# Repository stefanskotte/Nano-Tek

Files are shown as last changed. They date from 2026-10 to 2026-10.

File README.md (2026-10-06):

# Nano-Tek

**Note: This branch uses a PCB with the 34 pin floppy header is rotated 180 degrees to allow better fitment in some Amiga models. Everything else is the same with the main branch.**

A tiny, modern reimagining of the classic **Gotek** floppy-disk-drive emulator. Nano-Tek keeps the full feature set of a Gotek-style FDD emulator but packs it onto a board that is a fraction of the size, hence the name *Nano*-Tek.

<p align="center">
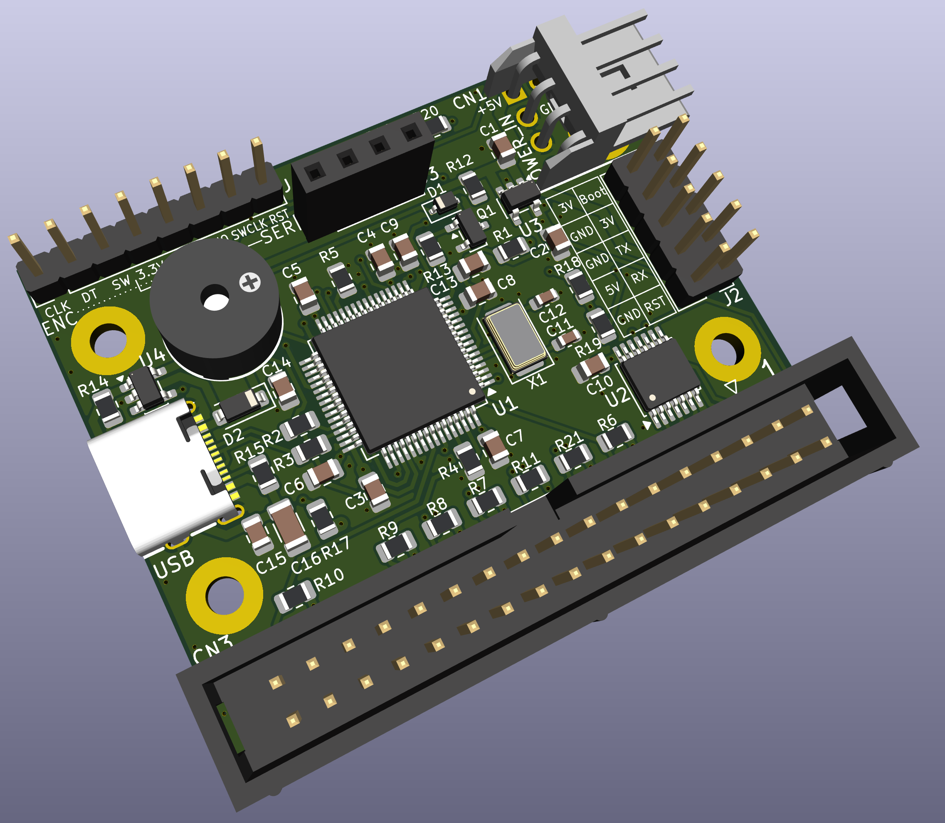
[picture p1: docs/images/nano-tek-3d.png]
Nano-Tek PCB, 3D render
  
</p>

The schematic is derived from the open-source [**OpenFlops**](https://github.com/SukkoPera/OpenFlops) design by *SukkoPera*, re-laid-out on a compact 4-layer PCB.

## Highlights

- **A lot smaller.** The board measures just **51 × 42 mm**, roughly half the footprint of a standard Gotek, while keeping the same 34-pin floppy interface.
- **FlashFloppy-compatible.** Built around the **STM32F105RBT6** (Cortex-M3) MCU, so it runs the popular [FlashFloppy](https://github.com/keirf/flashfloppy) firmware.
- **USB-C.** A modern USB-C port for the USB stick, fed through a current-limited power switch. It can also power the board on the bench.
- **OLED + rotary encoder** headers for a clean front-panel UI.
- **On-board passive buzzer** for the drive-step "click" and FlashFloppy's notification beeps.
- **Easy first flash.** Serial (with a BOOT0 jumper) and SWD headers on board, so a blank chip can be programmed without extra wiring.
- **4-layer PCB** for clean power and signal routing in a small area.

## Hardware overview

| Function | Part / Connector | Ref |
|---|---|---|
| Microcontroller | STM32F105RBT6 (LQFP-64) | U1 |
| Bus buffer | 74LCX07 (TSSOP-14) | U2 |
| 3.3 V regulator | AP2112K-3.3 (SOT-23-5) | U3 |
| USB power switch  | SY6288DAAC, current-limited (SOT-23-5) | U4 |
| USB bench power | B5819W Schottky diode (USB-C to +5 V) | D2 |
| Clock | 8 MHz crystal | X1 |
| Floppy interface  | 34-pin IDC header | CN3 |
| Power input | 4-pin power connector (171826-4) | CN1 |
| USB | USB-C (SMD) | CN2 |
| Display | OLED header (I²C) | J3 |
| Input + debug | Rotary encoder + SWD header (1×8) | J4 |
| Programming | Serial + BOOT0 header (2×5) | J2 |
| Audio | Passive buzzer, 9 mm (QMB-09B-05) | J1 |

See [`Nano-Tek.pdf`](Nano-Tek.pdf) for the full schematic and [`jlcpcb/production_files/BOM-Nano-Tek.csv`](jlcpcb/production_files/BOM-Nano-Tek.csv) for the complete bill of materials.

## Repository layout

```
Nano-Tek.kicad_pro      KiCad 10 project
Nano-Tek.kicad_sch      Schematic
Nano-Tek.kicad_pcb      PCB layout (4-layer)
Nano-Tek.pretty/        Project-specific footprint library
3dmodels/               3D models for connectors/parts
docs/                   Builder's guide, ST-LINK/V2 label
docs/images/            Rendered board images
jlcpcb/                 Gerbers, BOM and CPL for JLCPCB assembly
Nano-Tek.pdf            Schematic export
```

## Manufacturing

Ready-to-order production files for **JLCPCB** (4-layer) are provided in
[`jlcpcb/production_files/`](jlcpcb/production_files/):

- `GERBER-Nano-Tek.zip`: Gerber + drill files
- `BOM-Nano-Tek.csv`: bill of materials (with LCSC part numbers)
- `CPL-Nano-Tek.csv`: component placement / pick-and-place

## Firmware

A new board needs its first [FlashFloppy](https://github.com/keirf/flashfloppy) flash over **serial** (J2, BOOT0 jumper on pins 9–10) or **SWD** (J4, ST-Link). USB-C (DFU) does not work on a blank chip; it is only for recovery once FlashFloppy is on the board. Download the release zip from the [FlashFloppy releases page](https://github.com/keirf/flashfloppy/releases) and use `hex/flashfloppy-at415-st105-<ver>.hex` from it.

Step-by-step wiring for USB-serial adapters, PL2303 cables, ST-Link clones and the official ST-LINK/V2 is in the [builder's guide](docs/Nano-Tek_First_Firmware_Flash_Builders_Guide.pdf). After the first flash, update from a USB stick: copy the `.upd` file to the stick and hold the encoder button at power-on.

> **Note:** The USB-C port is a host port. Use a USB-A to USB-C data cable to power the board from a PC; USB-C to USB-C cables don't power it.

## Revisions

- **Rev 1.3** (October 2026): on-board passive buzzer, USB power switch, J2 serial pins now match the silkscreen, PA9/PA10/PA3 pull-ups, /MOTOR on PA15, NRST on J4 pin 8.
- **Rev 1.0–1.2:** J2 TX/RX are swapped against the silkscreen, and D1 must be fitted across the speaker (not in series) for sound. The builder's guide marks the steps that differ.

## Credits & license

- Schematic derived from [OpenFlops](https://github.com/SukkoPera/OpenFlops) by **SukkoPera**.
- Firmware: [FlashFloppy](https://github.com/keirf/flashfloppy) by **Keir Fraser**.
- Thanks to Vinny, Mesarim, Screemo, Kavanoz, Wrangler and Ordyne.

Please check the upstream OpenFlops project for its licensing terms; this derivative is shared in the same open-hardware spirit.

---

*Nano-Tek: the Gotek, shrunk.* Rev 1.3.

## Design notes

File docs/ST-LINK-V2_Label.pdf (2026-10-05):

# ST-LINK/V2 (20-pin) pinout labels

Print at 100% / Actual size. Check the 50 mm bar, then cut along the dashed lines.

50 mm

ST-LINK/V2 20-pin JTAG/SWD

1 VAPP | 3 TRST | 5 TDI | 7 SWDIO | 9 SWCLK | 11 NC | 13 SWO | 15 NRST | 17 NC | 19 3V3 out
2 VAPP | 4 GND | 6 GND | 8 GND | 10 GND | 12 GND | 14 GND | 16 GND | 18 GND | 20 GND

Pin 1 = red stripe. SWD: 1 VAPP to target 3.3V (required), 7, 9, GND. Never connect 19.

Main label - stick next to the 20-pin header, pin 1 (triangle) on the red-stripe side.

ST-LINK/V2 → Nano-Tek (SWD)

1 VAPP | → | J4-4 +3V3
4 GND | → | J4-5 GND
7 SWDIO | → | J4-6 SWDIO
9 SWCLK | → | J4-7 SWCLK
15 NRST | → | J2-1 NRST (opt.)

FlashFloppy on chip: BOOT0 high (J2 9-10) for SWD

Wiring card - keep with the ST-LINK or on the jumper-wire bundle.

ST-LINK/V2 20-pin JTAG/SWD

1 VAPP | 3 TRST | 5 TDI | 7 SWDIO | 9 SWCLK | 11 NC | 13 SWO | 15 NRST | 17 NC | 19 3V3 out
2 VAPP | 4 GND | 6 GND | 8 GND | 10 GND | 12 GND | 14 GND | 16 GND | 18 GND | 20 GND

Pin 1 = red stripe. SWD: 1 VAPP to target 3.3V (required), 7, 9, GND. Never connect 19.

Compact copy (7 mm cells)

Finding pin 1 on the box header with a meter (probe unplugged):
- The even row is the one where 9 pins (4, 6 ... 20) are all GND; its one non-GND end pin is pin 2.
- Pin 1 is next to pin 2 in the other row (pins 1 and 2 are both VAPP and read shorted).
VAPP only senses the target voltage; the ST-LINK/V2 does not power the target.
Pin 19 is the probe's own 3.3 V output - leave it unconnected.
Source: ST UM1075, Table 4 (JTAG/SWD cable connections).

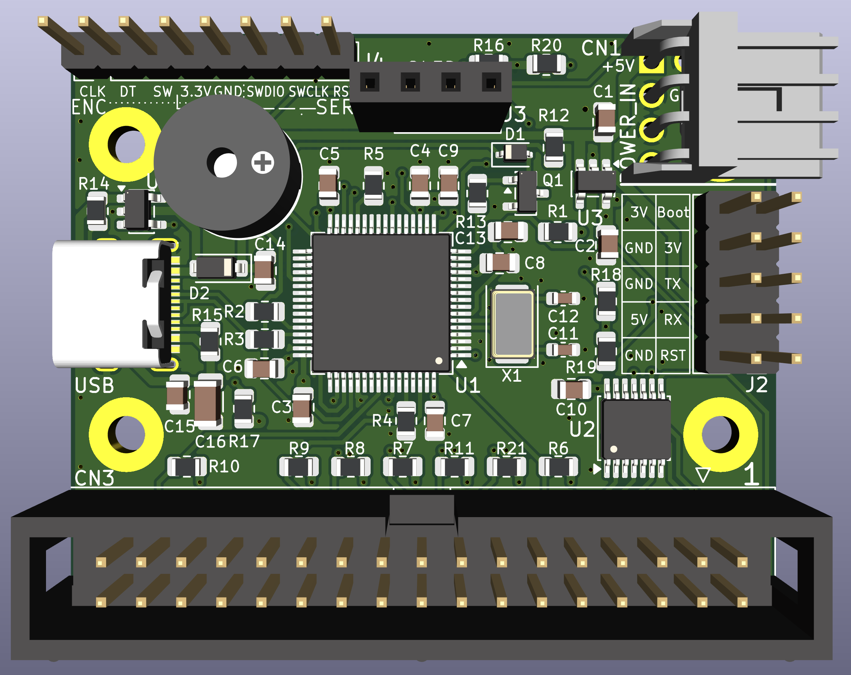
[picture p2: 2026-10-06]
docs/images/nano-tek-top.png

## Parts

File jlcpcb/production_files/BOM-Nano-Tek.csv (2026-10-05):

Comment | Designator | Footprint | LCSC | Quantity
100nF | C10,C13,C4,C5,C6,C7,C8 | C_0805_2012Metric | C49678 | 7
10K | R16,R17,R18,R19,R20 | R_0805_2012Metric | C17414 | 5
10uF | C14,C15,C2,C3,C9 | C_0805_2012Metric | C15850 | 5
1K | R10,R11,R13,R21,R6,R7,R8,R9 | R_0805_2012Metric | C17513 | 8
1N4148WS | D1 | D_SOD-323 | C2128 | 1
1uF | C1 | C_0805_2012Metric | C28323 | 1
22 | R12,R2,R3 | R_0805_2012Metric | C17561 | 3
30pF | C11,C12 | C_0603_1608Metric | C1658 | 2
47uF 10V | C16 | C_1206_3216Metric | C96123 | 1
4K7 | R1,R4,R5 | R_0805_2012Metric | C17673 | 3
51K | R14,R15 | R_0805_2012Metric | C17737 | 2
74LCX07 | U2 | TSSOP-14_4.4x5mm_P0.65mm | C2676034 | 1
8MHz | X1 | Crystal_SMD_5032-2Pin_5.0x3.2mm | C115962 | 1
AP2112K-3.3 | U3 | SOT-23-5 | C23380830 | 1
B5819W SL | D2 | D_SOD-123 | C8598 | 1
Buzzer | J1 | BUZ-TH_BD9.0-P4.00-D0.6-FD | C161819 | 1
Encoder+SER | J4 | PinHeader_1x08_P2.54mm_Vertical | C5383116 | 1
Floppy 34 | CN3 | IDC-Header_2x17_P2.54mm_Vertical | C601943 | 1
MMBT3904 | Q1 | SOT-23 | C20526 | 1
OLED | J3 | PinSocket_1x04_P2.54mm_Vertical | C41431927 | 1
POWER_IN | CN1 | 171826-4 | C590635 | 1
STM32F105RBT6 | U1 | LQFP-64_10x10mm_P0.5mm | C8349 | 1
SY6288DAAC | U4 | SOT-23-5 | C83700 | 1
USB | CN2 | USB-C-SMD_TYPE-C16PIN | C393939 | 1
USB_Prog | J2 | PinHeader_2x05_P2.54mm_Vertical | C5383106 | 1

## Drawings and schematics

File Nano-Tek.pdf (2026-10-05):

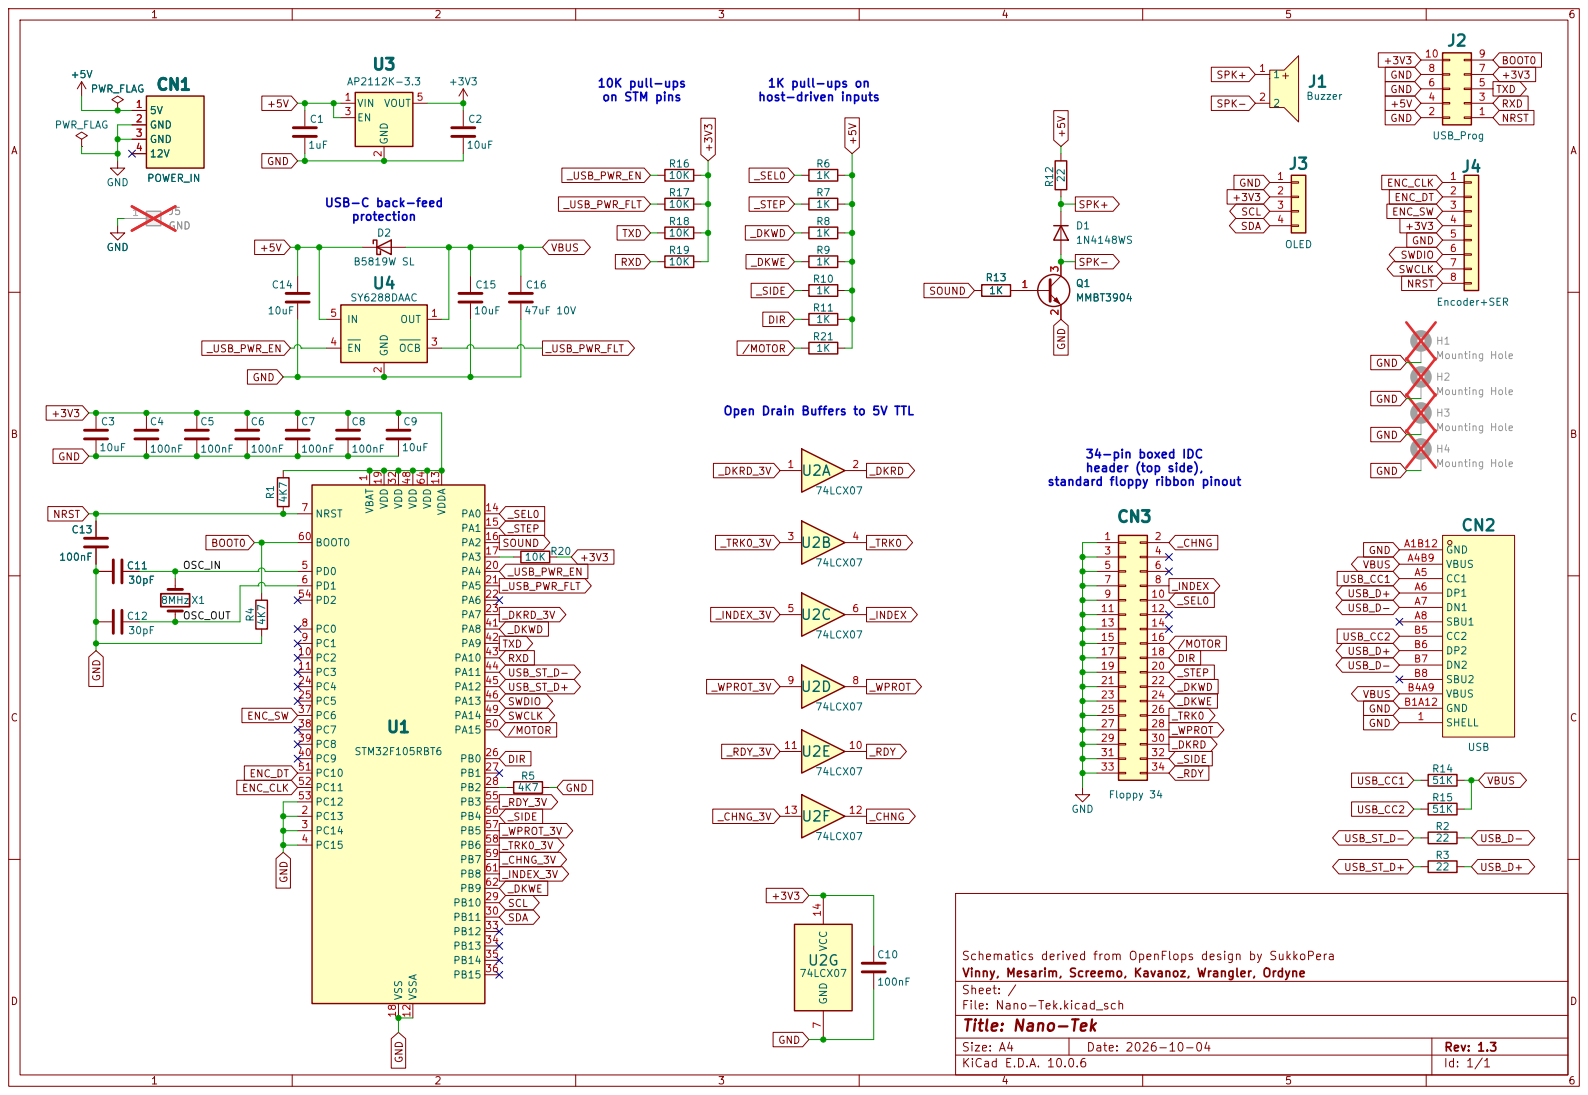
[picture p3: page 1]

2 3 Q1MMBT3904 H3Mounting Hole H4Mounting Hole H2Mounting Hole H1Mounting Hole 1

Open Drain Buffers to 5V TTL

34-pin boxed IDC
header (top side),
standard floppy ribbon pinout

Schematics derived from OpenFlops design by SukkoPera
Vinny, Mesarim, Screemo, Kavanoz, Wrangler, Ordyne
Sheet: /
File: Nano-Tek.kicad_sch
Title: Nano-Tek

Size: A4 | Rev: 1.3
KiCad E.D.A. 10.0.6 | Id: 1/1

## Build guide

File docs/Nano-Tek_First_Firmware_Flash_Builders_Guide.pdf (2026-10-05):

# Nano-Tek: First Firmware Flash

Prepared by Kavanoz using Claude AI.
Builder's guide for all board revisions · October 2026

A freshly built Nano-Tek has a blank STM32. You flash FlashFloppy onto it once, with a USB-serial adapter or an ST-Link. After that, FlashFloppy updates itself from a USB stick.

USB-C can't do the first flash. The STM32's USB programming mode (DFU) does not start on a blank chip. Use one of the options below.

Steps that differ between boards are marked Only applies to Rev 1.0–1.2 or Only applies to Rev 1.3 and later . The revision is printed on the back of the board.

## What you need

Firmware. From the FlashFloppy releases page, (https://github.com/keirf/flashfloppy/releases) download the release file flashfloppy-<version>.zip , not "Source code (zip)". Inside it you need:

hex/flashfloppy-at415-st105-<version>.hex for the first flash.
flashfloppy-<version>.upd for later updates from a USB stick.

One programmer (any one of these):

Option | Programmer | Connects to | Software
A (easiest) | 3.3 V USB-serial adapter: CP2102, CH340, FT232 or FT2232H | J2 | STM32CubeProgrammer (Windows, macOS, Linux) or stm32flash
B | PL2303 USB-serial cable (4 wires) | J2 | Same as A; Windows 10/11 may need the PL2303 Legacy Updater
C | Cheap ST-Link V2 clone (USB stick shape) | J4 | STM32 ST-LINK Utility or OpenOCD
D | Official ST-LINK/V2 (20-pin ribbon) | J4 | STM32CubeProgrammer

Also: 3–4 female DuPont jumper wires, one 2.54 mm jumper cap, and power for the board: a USB-A to USB-C cable from a PC or USB charger, or the floppy power cable. USB-C to USB-C cables don't power the board.

Downloads: FlashFloppy releases (https://github.com/keirf/flashfloppy/releases) · FlashFloppy wiki (https://github.com/keirf/flashfloppy/wiki) · STM32CubeProgrammer (https://www.st.com/en/development-tools/stm32cubeprog.html) · ST-LINK driver (STSW-LINK009) (https://www.st.com/en/development-tools/stsw-link009.html) · STM32 ST-LINK Utility (STSW-LINK004) (https://www.st.com/en/development-tools/stsw-link004.html) · OpenOCD, xPack build (https://github.com/xpack-dev-tools/openocd-xpack/releases) · stm32flash (https://sourceforge.net/projects/stm32flash/) · PL2303 Legacy Updater (https://github.com/johnstevenson/pl2303-legacy) · ST-LINK/V2 manual UM1075 (https://www.st.com/resource/en/user_manual/um1075-stlinkv2-incircuit-debuggerprogrammer-for-stm8-and-stm32-stmicroelectronics.pdf)

## The two headers

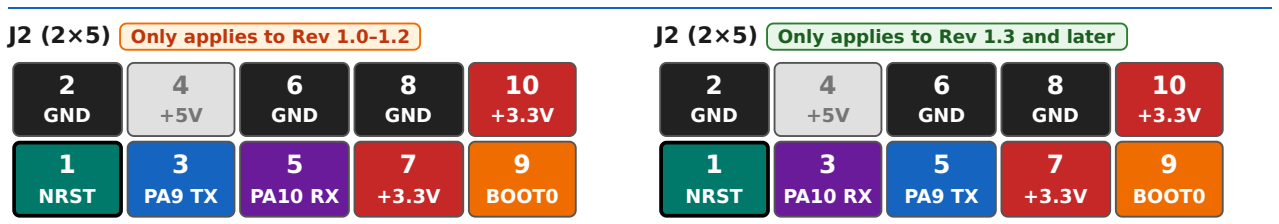
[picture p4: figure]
J2 (2×5) Only applies to Rev 1.0–1.2; 2 GND; 6 GND; 8 GND; NRST; BOOT0

RX and TX are swapped on these boards and don't match the silkscreen. Wire by this diagram, not by the board labels.

J2 (2×5) Only applies to Rev 1.3 and later

Matches the silkscreen. Labels name the board's own pins, so the adapter's TX goes to the pin marked RX.
On every revision: jumper cap on J2 9–10 = BOOT0 high (programming mode). Pin 4 (+5V) is only for optional bench power (Option B). Pin numbers follow the schematic; pin 1 has the square pad.
Nano-Tek: First Firmware Flash (builder's guide) | Page 1 of 4

J4: encoder + SWD header, all revisions

Encoder on 1–5, SWD on 6–7; with the encoder plugged in, take GND from J2-2. Only applies to Rev 1.3 and later pin 8 = NRST (dashed); Rev 1.0–1.2 have 7 pins.

Power rules: read before plugging anything in
Only applies to Rev 1.0–1.2 Power the board from USB-C or from the floppy power connector (CN1), never both. USB-C power is wired straight to the board's 5 V, so the PC and the Amiga supplies would feed into each other.
Only applies to Rev 1.3 and later USB-C feeds the board through a diode, and the USB power switch stays off while you program, so CN1 may stay connected. Don't plug a PC into USB-C while FlashFloppy is running from CN1 power.
Never use a programmer's 3.3 V pin as power. A serial cable's 5 V lead may go to J2-4, but only with CN1 and USB-C unplugged.
BOOT0 is only read at power-up: fit the jumper cap before powering the board.

## Option A: USB-serial adapter (recommended)

This uses the bootloader built into every STM32: three wires and the BOOT0 jumper. Set the adapter to 3.3 V logic (many have a 3.3/5 V jumper).

Adapter | J2 on Rev 1.0–1.2 | J2 on Rev 1.3 and later
TX | pin 5 (PA10 RX) | pin 3 (PA10 RX)
RX | pin 3 (PA9 TX) | pin 5 (PA9 TX)
GND | pin 2 | pin 2

Don't connect the adapter's 3.3 V or 5 V pins. On an FT2232H board, use channel A: AD0 = TX, AD1 = RX.

1. Fit the jumper cap on J2 pins 9–10 (BOOT0).
2. Power the board. The OLED stays blank, which is expected.
3. Open STM32CubeProgrammer and select UART. Choose the adapter's COM port, baud rate 115200, parity Even, 8 data bits, 1 stop bit, flow control off. Click Connect. You should see Chip ID 0x418.
4. Open Erasing & Programming, browse to the .hex file, tick Verify programming, and click Start Programming.
5. Click Disconnect, remove the jumper cap and the wires, and power-cycle. FlashFloppy appears on the OLED.

Command-line versions (replace the port and version):

STM32_Programmer_CLI -c port=COM5 br=115200 P=EVEN -w flashfloppy-at415-st105-3.44.hex -v stm32flash -b 115200 -w flashfloppy-at415-st105-3.44.hex -v /dev/ttyUSB0

Tips: if Connect fails, power-cycle the board before retrying, because the bootloader locks onto the first interface it hears from. If it still fails, swap TX and RX.

## Option B: PL2303 USB-serial cable

The common 4-wire PL2303 cable works just like Option A. On Windows 10/11, older and clone PL2303 chips show Code 10 or "PL2303HXA PHASED OUT" in Device Manager until you give them a legacy driver:

1. Install the PL2303 Legacy Updater, (https://github.com/johnstevenson/pl2303-legacy) plug in the cable, run "PL2303 Legacy Updater" and pick the driver it offers (3.3.11.152 for HXA/XA chips, 3.8.36.2 for TA/TB).
2. Device Manager → Ports should now show "Prolific USB-to-Serial Comm Port (COMx)" with no warning. If Windows Update swaps the driver back later, run the updater again.
Cable wire (usual color) | J2 on Rev 1.0–1.2 | J2 on Rev 1.3 and later
TX (green) | pin 5 | pin 3
RX (white) | pin 3 | pin 5
GND (black) | pin 2 | pin 2
+5V (red) | pin 4 (optional) | pin 4 (optional)

Wire colors vary between cables, so check yours. The red +5V lead on J2-4 can power the board on its own, which is handy on the bench, but only with CN1 and USB-C unplugged; otherwise leave it unconnected. 3.3 V and 5 V logic cables both work (PA9 and PA10 are 5 V tolerant). Then program exactly as in Option A, steps 1–5.

## Option C: cheap ST-Link V2 clone (SWD)

A blank chip accepts SWD straight away: no BOOT0 jumper and no serial wires needed. Wire by the labels printed on the clone's case.

Clone | Nano-Tek
GND | J4-5 (or J2-2)
SWDIO | J4-6
SWCLK | J4-7

Leave the clone's 3.3 V and RST pins unconnected. Power the board from USB-C or CN1.
Install ST's ST-LINK driver (STSW-LINK009).
STM32 ST-LINK Utility: Target → Connect, then Target → Program & Verify. Pick the .hex , tick Verify and Reset after programming, then Start.
OpenOCD (xPack build), one command:

openocd -f interface/stlink.cfg -f target/stm32f1x.cfg -c "adapter speed 100" -c "program flashflopp y-at415-st105-3.44.hex verify reset exit"

STM32CubeProgrammer often refuses clones. Don't let any ST tool "upgrade" a clone's firmware. Clones built on non-ST chips can be bricked.
Only one program can use the ST-Link at a time; close the others first.

## Option D: official ST-LINK/V2 (20-pin)

Same as Option C plus one wire: the probe must see the board's 3.3 V on its pin 1 (VAPP), or it won't connect. It does not power the board.

ST-LINK/V2 pin | Signal | Nano-Tek
1 | VAPP (target voltage sense) | J4-4 or J2-7 (+3.3V), required
4 (or any even pin 4–20) | GND | J4-5 or J2-2
7 | SWDIO | J4-6
9 | SWCLK | J4-7
15 | NRST (optional) | J2-1, or J4-8 on Rev 1.3 and later
19 | Probe's own 3.3 V output | Do not connect

Pin 1 is on the red-stripe side of the ribbon cable. In STM32CubeProgrammer choose ST-LINK, port SWD, mode Normal, click Connect, then program as in Option A step 4. A printable label for the probe is in the Nano-Tek repository: docs/ST-LINK-V2_Label.pdf .

## After the first flash

Updates. Copy flashfloppy-<version>.upd to the root of the USB stick (only one .upd file; two give error E02). Hold the encoder button while powering on and follow the OLED.

Re-flashing with SWD later. FlashFloppy switches SWD off when it runs, so fit the BOOT0 jumper before powering the board.

Rescue over USB-C. Once FlashFloppy has been flashed, the chip stays non-blank (updates never erase FlashFloppy's updater), so USB-C programming works for recovery:
1. Only applies to Rev 1.0–1.2 Tie PA9 to +3.3V with a DuPont wire from J2-3 to J2-7, and unplug the floppy power (CN1). Rev 1.3 and later have the PA9 pull-up on the board, so no wire is needed.
2. Fit the jumper cap on J2 9–10. Connect USB-C to the PC with a USB-A to USB-C data cable. Charge-only cables show nothing.
3. Windows shows STM32 BOOTLOADER. In STM32CubeProgrammer choose USB, Connect, and program the .hex as above.
4. Remove the jumper cap (and the PA9 wire), then power-cycle.

## Troubleshooting

Problem | Fix
Serial: Connect times out | Check TX/RX against the diagram for your board revision, or swap them. Check BOOT0 is fitted. Power-cycle, then Connect again. Parity must be Even.
OLED shows FlashFloppy while you try to program | BOOT0 wasn't fitted at power-up. Fit it and power-cycle.
ST-Link: "unable to connect to the target" | Check the three wires and the clone's labels; try swapping SWDIO/SWCLK. If FlashFloppy is already on the chip, fit BOOT0.
OpenOCD: "LIBUSB_ERROR_ACCESS" | Another program has the ST-Link open. Close STM32CubeProgrammer and ST-LINK Utility.
Official ST-LINK shows 0 V target | Pin 1 (VAPP) isn't wired to +3.3V.
USB-C: nothing appears on the PC | Blank chip (use Option A, B, C or D), charge-only cable, missing PA9-to-3.3V wire (Rev 1.0–1.2), USB-C to USB-C cable, or BOOT0 not fitted.
Update stops with E02 | More than one .upd file on the stick. Keep one.
PL2303: Code 10 or "PHASED OUT" in Device Manager | Run the PL2303 Legacy Updater and pick the legacy driver; run it again after Windows updates.

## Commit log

2026-08-03 Add README with 3D board render
    Document the Nano-Tek board (55x42mm, STM32F105-based, FlashFloppy-compatible
    Gotek replacement derived from OpenFlops) and add a raytraced 3D PCB render.
2026-08-12 Rev 1.1
    OLED and Serial pin header changes.
    Additional GND point for connecting 2 pin +5V input instead of using a Berg.
    [BOM-Nano-Tek.csv, Nano-Tek.kicad_pcb, Nano-Tek.kicad_sch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]
2026-08-12 Rev 1.1
    [Nano-Tek.kicad_pcb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]
2026-08-22 Rev 1.2
    Board shrunk to the length of the floppy header.
    [BOM-Nano-Tek.csv, Nano-Tek.kicad_pcb, Nano-Tek.kicad_sch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]
2026-10-05 Rev 1.3
    Various updates listed in readme file
    [BOM-Nano-Tek.csv, Nano-Tek.kicad_pcb, Nano-Tek.kicad_sch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]
2026-10-06 Rev 1.3 with Rotated Floppy Header
    Rev 1.3 with Rotated Floppy Header for better fit in some Amiga models
    [Nano-Tek.kicad_pcb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]
